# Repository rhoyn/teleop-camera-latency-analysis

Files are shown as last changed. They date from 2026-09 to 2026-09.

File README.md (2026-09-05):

# teleop-camera-latency-analysis

Blog post: [Low latency eyes](https://rhoyn.com/low-latency-eyes?utm_source=github)

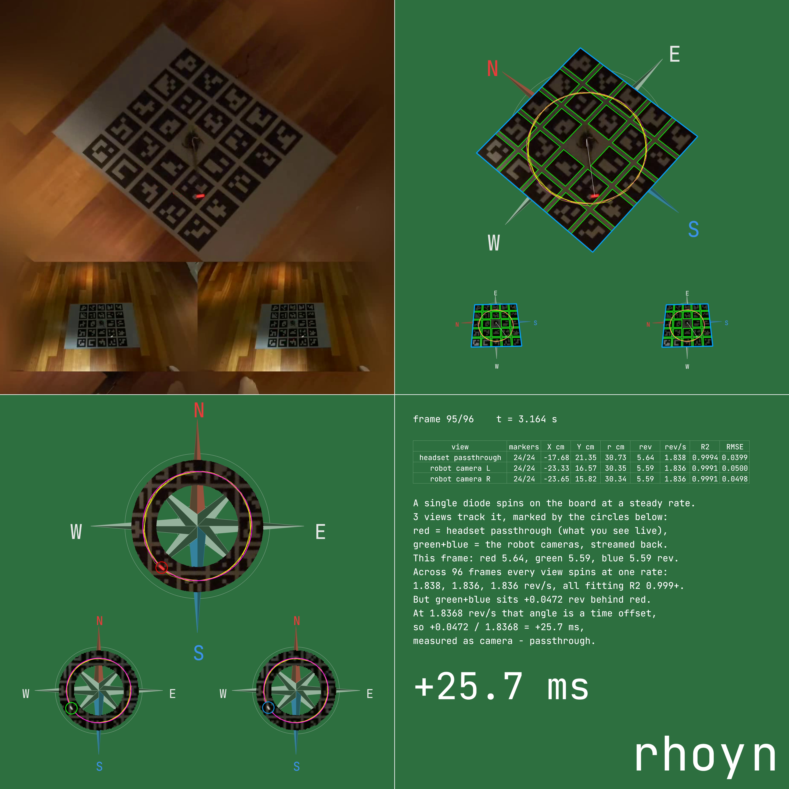
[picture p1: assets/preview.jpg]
The four-panel output: the raw view, the fitted overlay, the diode's orbit band, and the measurement table with the latency


https://github.com/user-attachments/assets/50d515f3-5a79-4a9a-a9fb-55cd01d475e2

## Problem statement

This is what the operator sees while teleoperating the humanoid: the room in
front of them through the headset's own passthrough, with the robot's cameras
floating inside it. Both show the same scene from almost the same place, and
that is what makes the lag visible — move, and the robot's view of the move
arrives a little after the live one.

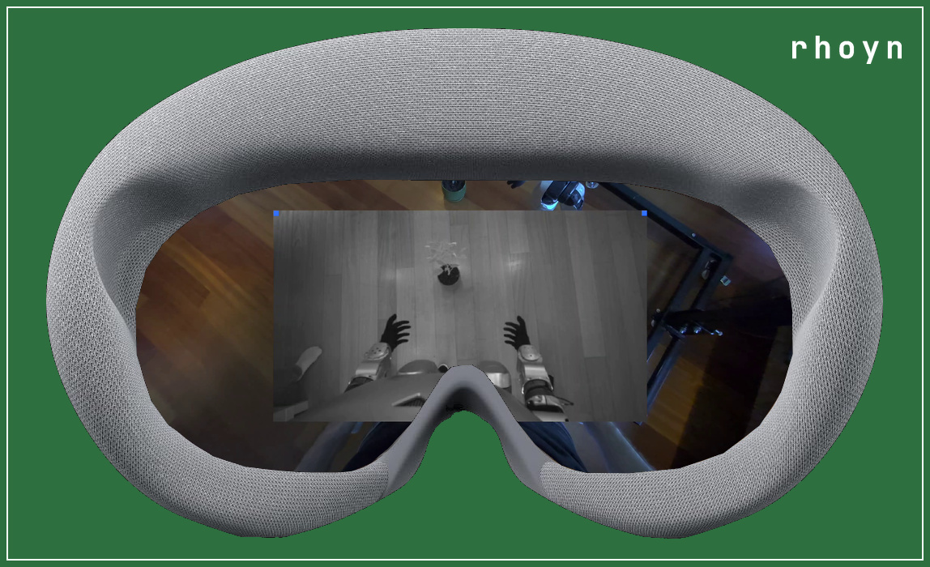
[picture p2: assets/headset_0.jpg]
Inside the headset while teleoperating: the passthrough view of the room, with the robot's camera feed floating in the middle of it showing the same floor and the robot's own hands


The robot feed is stereo, a separate image per eye, which is what gives it
depth and exactly what a flat screen cannot reproduce. It can be switched to a
side-by-side pair of the two eyes, which is what a screenshot can show:

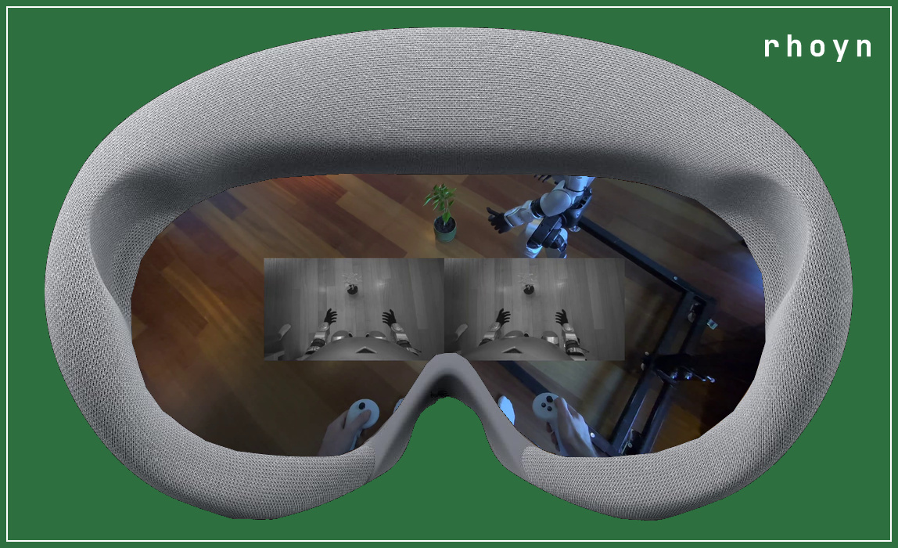
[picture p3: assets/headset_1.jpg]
The same view switched out of stereo: the robot's left and right camera images shown side by side rather than one per eye


Noticing the lag is not measuring it. For that the floor gets one printed ArUco
board with an LED on an arm spinning around its centre, and the session is
recorded through the headset. A single frame of that recording holds the whole
measurement:

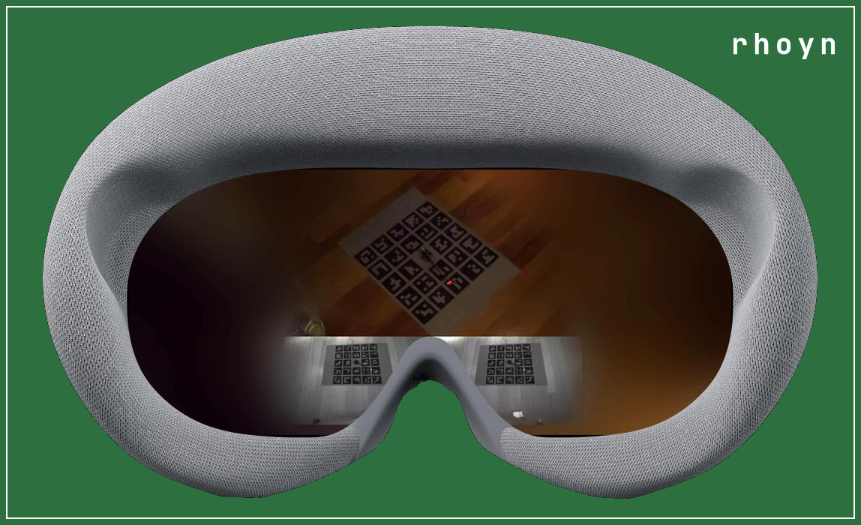
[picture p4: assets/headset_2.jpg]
A single frame of one recording, made inside the headset: the passthrough view of the board on the floor with the spinning LED lit red, and the robot cameras' stereo preview floating below it, showing the same board as it arrives over the teleoperation stack


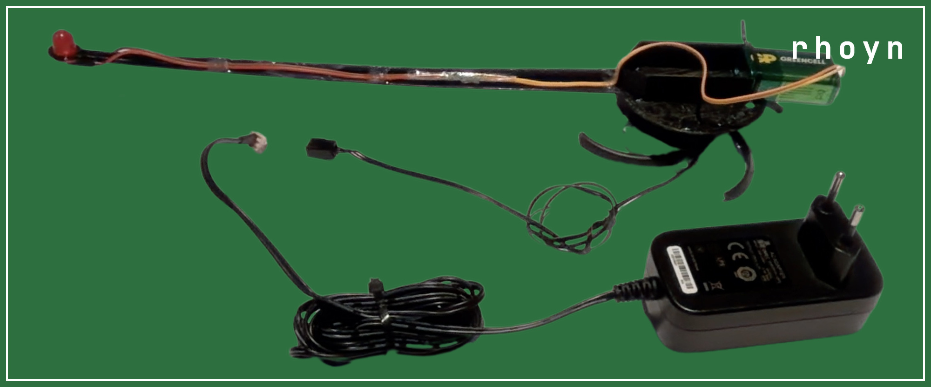
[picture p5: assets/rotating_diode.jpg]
The assembled spinning arm: a red LED at the tip of the printed arm, the battery that powers it strapped to the hub, and the motor and its supply


That recording is what this software processes.

## What it measures

Measures end-to-end video latency of a teleoperation stack from a single
recording, by watching one physical spinning LED through every camera path at
once.

The program prints one number — the latency in milliseconds — on stdout, and
writes a four-panel video showing how it got there.

The number is signed, always as **camera minus passthrough**: positive means the
robot camera view is that far behind the live passthrough, negative means it is
that far ahead. A stream fast enough to tie with the headset's own passthrough
sits near zero and its sign will wander between clips, which is what a reading
below the method's noise floor looks like — treat a small number as "no
measurable difference", not as a confident lead.

## Capture rig

- `aruco_board_A0.pdf` — the marker board, printed at A0. It is a 5x5 grid
  from `DICT_4X4_50` with the centre marker omitted to leave room for the
  spinning arm's axle. The dimensions the program assumes are compiled in near
  the top of `main.cpp` (`BOARD_WIDTH_CM`, `MARKERS_PER_SIDE`, and the rest);
  if you print at a different size, change them to match.
- `rotating_diode/` — the spinning arm, as OpenSCAD source plus prebuilt STLs.
  `rotating_diode/run.sh` regenerates the STLs (whole, plus split left/right
  halves for smaller print beds). It carries a battery and a red LED, and the
  program expects the LED to orbit at `DIODE_ORBIT_RADIUS_CM`. The parts and
  the motor it spins on are listed in
  [rotating_diode/BOM.md](rotating_diode/BOM.md).

The arm's exact speed doesn't need to be known or held constant between runs —
it's measured from the video, and only has to be steady across a single clip.

## How it works

The subject is one printed ArUco board with an LED on an arm spinning around
its centre, and one frame of the headset recording holds that board twice over,
or three times for a stereo pair:

- the **headset passthrough** — the operator's own view of the room, as close
  to realtime as the headset gets, showing the LED roughly where it is now,
  and
- the **robot camera** preview floating in front of it (here a stereo
  **L**/**R** pair) — the same LED, but arriving over the teleoperation
  stack, so showing where it was some milliseconds ago.

One recorder, one instant, one physical LED. Nothing has to be instrumented
and no clocks have to be synchronised: the only thing separating the two
pictures of the board is the latency of the stream between them.

The LED spinning is what turns that separation into a number. Where the arm
points is a clock hand, and the two views are reading the same hand at
different moments, so the angle between them is the delay — once the arm's
speed is known, and that is measured from the video too.

For each frame the program fits the board pose from the ArUco markers, maps
the LED blob into board coordinates, and records its angle. Unwrapped over the
clip, each view's angle-versus-time is a straight line. All views share the
same angular speed — it's one physical LED — so the fitted lines differ only
in phase. Dividing that phase gap by the shared angular speed converts it into
time, and fitting over every frame rather than comparing frame to frame is
what averages the per-frame noise out.

Fitting the whole clip is also why the result has sub-frame resolution: the
measurement is not quantised to the recording's frame interval.

## Results

Every clip in `inputs/`, in milliseconds, signed as **camera minus
passthrough**: positive means the robot camera view sits that far behind the
live passthrough. Row `3` is `inputs/<stack>-3.mp4`, and its four-panel render
is `outputs/<stack>-3.mp4`.

| # | rhoyn | XRoboToolkit |
|---|---|---|
| 0 | -4.3 | +25.7 |
| 1 | -2.4 | +31.7 |
| 2 | +6.9 | +40.5 |
| 3 | -2.7 | +39.7 |
| 4 | +5.5 | +41.2 |
| 5 | -1.8 | +28.7 |
| 6 | -3.8 | +35.0 |
| 7 | +3.1 | +35.6 |
| **median** | **-2.1** | **+35.3** |
| **mean** | **+0.1** | **+34.8** |

### Comparison

| video stack | recordings | median latency | vs rhoyn |
|---|---|---|---|
| rhoyn Teleop + stock Unitree G1 D435 | 8 | **-2.1 ms** | — |
| XRoboToolkit Orin Video Sender + ZED Mini | 8 | **+35.3 ms** | **+37.4 ms slower** |

The two stacks do not overlap: rhoyn spans -4.3 to +6.9 ms and the alternative
+25.7 to +41.2 ms, so every rhoyn clip is ahead of every clip from the
alternative.

The last column is a difference rather than the "Nx slower" ratio the hands
analysis uses, because a ratio would be meaningless here. rhoyn's clips
straddle zero and their sign wanders between takes, which is exactly what a
stream fast enough to tie with the headset's own passthrough looks like — so
-2.1 ms means "no measurable difference", not a 2 ms lead, and dividing by a
figure sitting on the noise floor would manufacture a ratio out of nothing.
What the recordings do support is the gap: the alternative arrives about 37 ms
behind.

### How much lower

Pair every rhoyn clip with every clip from the alternative — 8 x 8, so 64
pairs — subtract, and take the median of the 64 differences. That number is
**34.7 ms**: the alternative's display latency is 34.7 ms higher than rhoyn's.

Both stacks were recorded the same way and measured by this program with the
same board and the same constants, so every one of those 64 subtractions is
between two numbers produced by one instrument. All 64 come out positive,
the smallest 18.8 ms and the largest 45.5 ms, because the two sets of clips
do not overlap.

## Build and run

```sh
make                       # -> build/teleop-camera-latency-analysis
./run.sh                   # every clip in inputs/, results into outputs/
./run.sh inputs/clip.mp4   # or specific clips
```

Or directly:

```sh
build/teleop-camera-latency-analysis --input inputs/clip.mp4 --output outputs/clip.mp4
```

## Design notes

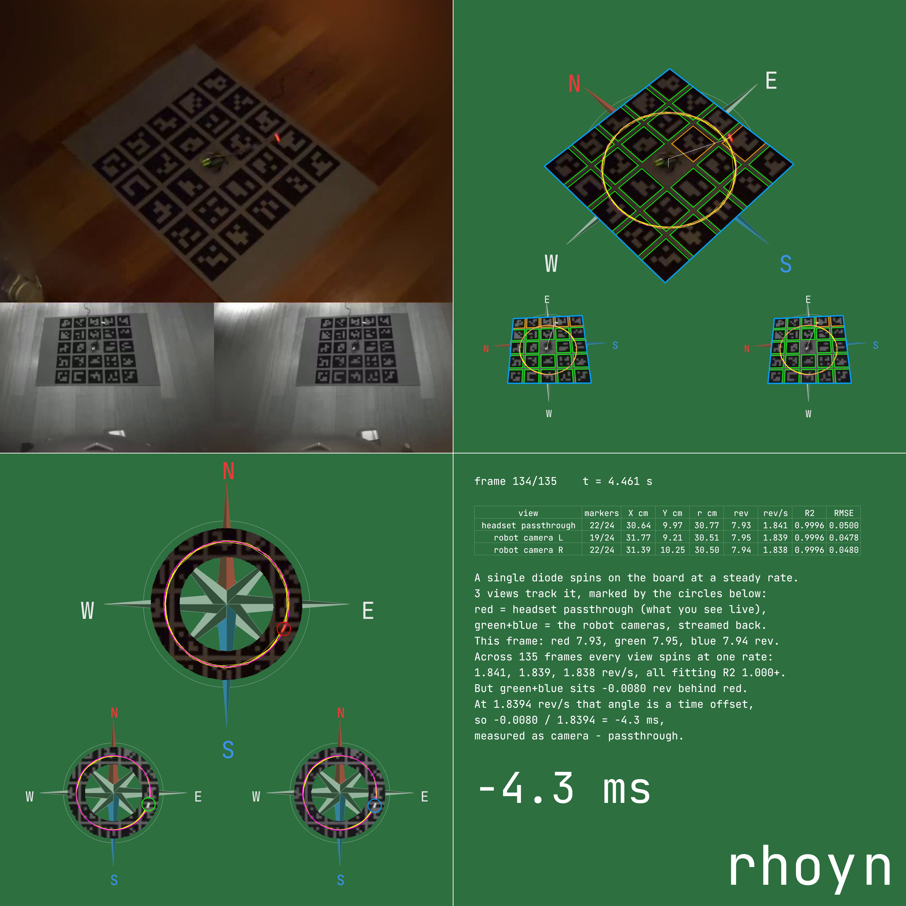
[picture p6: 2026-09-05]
assets/preview_rhoyn.jpg

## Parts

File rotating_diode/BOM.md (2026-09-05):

# Rotating diode — bill of materials

Everything needed to build the spinning arm and the motor that turns it.

| # | Part | Notes |
|---|---|---|
| 1 | Printed arm | `rotating_diode.stl`, or `rotating_diode_left.stl` + `rotating_diode_right.stl` glued at the cut plane for smaller beds |
| 2 | 10 mm red LED | Press-fits the 10.5 mm hole at the tip of the arm; this is the blob the program tracks |
| 3 | Resistor, 270 Ω | 5-band, red-violet-black-black-brown (2-7-0, x1, +/-1%). In series with the LED |
| 4 | 9 V battery | Rides in the walled pocket on the disk and turns with it, so no slip ring is needed |
| 5 | 9 V battery clip | Snap connector, wires run along the arm to the LED |
| 6 | 120 x 120 mm fan | The motor — see below |
| 7 | 12 V DC power supply | Drives the fan. A barrel-jack adapter with a fan connector, or any 12 V supply wired to the fan's two power leads |
| 8 | Glue and tape | To bond the arm to the fan hub and dress the LED wiring down the arm |

## The motor

The fan is used as a bare motor, not as a fan:

1. Cut away the square frame, leaving the hub and its spider.
2. Remove the blades from the hub.
3. Glue the bottom of the printed disk to the hub.

Powered from the 12 V supply, the hub spins the arm. The speed doesn't need to
be set or known — it's measured from the video, and only has to stay steady
across a single clip.

## The LED circuit

Battery -> clip -> 270 Ω resistor -> LED -> back to the battery. At 9 V with a
red LED that's roughly 26 mA, which is bright enough to saturate in the
recordings while staying inside a 10 mm LED's rating. The whole circuit rotates
with the arm, so nothing has to be fed across the rotating joint.

The assembled arm, motor hub and 12 V supply

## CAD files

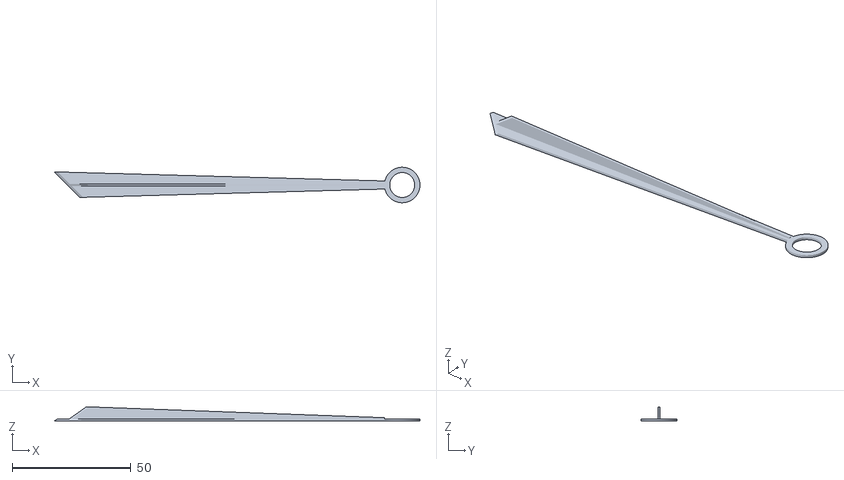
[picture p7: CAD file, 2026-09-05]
rotating_diode/rotating_diode_right.stl
154.4 x 15.0 x 6.10

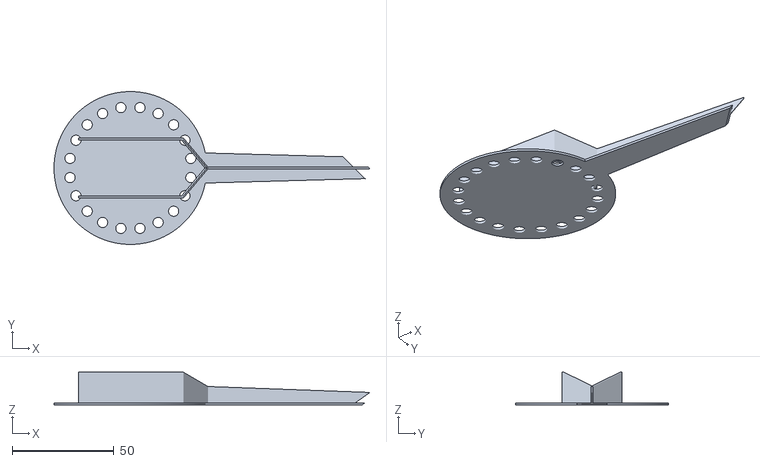
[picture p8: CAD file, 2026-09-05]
rotating_diode/rotating_diode_left.stl
155.1 x 75.0 x 16.0

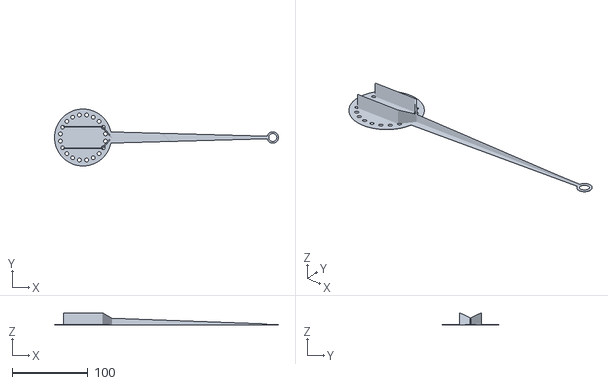
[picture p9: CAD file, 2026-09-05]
rotating_diode/rotating_diode.stl
295.0 x 75.0 x 16.0

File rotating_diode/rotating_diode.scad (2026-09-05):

$fn = 180;

disk_dia            = 75;
disk_h              = 1;
disk_hole_dia       = 5;
disk_hole_count     = 20;
disk_hole_edge_gap  = 5;
disk_hole_ring_r    = disk_dia / 2 - disk_hole_edge_gap - disk_hole_dia / 2;

battery_len    = 50;
battery_width  = 26.5;
fit_clearance  = 1.0;
wall_th        = 1;
wall_h         = 15;
wall_len       = battery_len + fit_clearance;
wall_y         = (battery_width + fit_clearance) / 2 + wall_th / 2;

stick_tip_x    = 250;
stick_w_base   = 15;
stick_w_tip    = 3;
stick_overlap  = 5;
stick_base_x   = disk_dia / 2 - stick_overlap;
tip_pad_dia    = 15;
tip_hole_dia   = 10.5;
rib_w          = 1;
rib_h_base     = 8;
rib_h_tip      = 0.5;
rib_base_x     = disk_dia / 2;
rib_tip_x      = stick_tip_x - tip_pad_dia / 2;

cut_x     = (-disk_dia / 2 + stick_tip_x + tip_pad_dia / 2) / 2;
cut_w     = 0.1;
cut_yaw   = 45;
cut_tilt  = 45;

module disk() {
    difference() {
        cylinder(h = disk_h, d = disk_dia);
        for (i = [0 : disk_hole_count - 1]) {
            angle = (i + 0.5) * 360 / disk_hole_count;
            translate([disk_hole_ring_r * cos(angle), disk_hole_ring_r * sin(angle), -1])
                cylinder(h = disk_h + 2, d = disk_hole_dia);
        }
    }
}

module battery_walls() {
    for (side = [1, -1])
        translate([0, side * wall_y, disk_h + wall_h / 2])
            cube([wall_len, wall_th, wall_h], center = true);
}

module stick() {
    difference() {
        union() {
            linear_extrude(height = disk_h)
                polygon([[stick_base_x,  stick_w_base / 2],
                         [stick_tip_x,   stick_w_tip / 2],
                         [stick_tip_x,  -stick_w_tip / 2],
                         [stick_base_x, -stick_w_base / 2]]);
            translate([stick_tip_x, 0, 0])
                cylinder(h = disk_h, d = tip_pad_dia);
            translate([0, rib_w / 2, disk_h])
                rotate([90, 0, 0])
                    linear_extrude(height = rib_w)
                        polygon([[rib_base_x, 0],
                                 [rib_tip_x,  0],
                                 [rib_tip_x,  rib_h_tip],
                                 [rib_base_x, rib_h_base]]);
        }
        translate([stick_tip_x, 0, -1])
            cylinder(h = disk_h + 2, d = tip_hole_dia);
    }
}

module rib_wall_braces() {
    for (side = [1, -1])
        hull() {
            translate([rib_base_x, 0, disk_h + rib_h_base / 2])
                cube([rib_w, rib_w, rib_h_base], center = true);
            translate([wall_len / 2, side * wall_y, disk_h + wall_h / 2])
                cube([wall_th, wall_th, wall_h], center = true);
        }
}

module at_cut_plane() {
    translate([cut_x, 0, disk_h])
        rotate([0, cut_tilt, cut_yaw])
            children();
}

module assembly() {
    difference() {
        union() {
            disk();
            battery_walls();
            stick();
            rib_wall_braces();
        }
        at_cut_plane()
            cube([cut_w, disk_dia + 20, (disk_h + wall_h) * 4], center = true);
    }
}

module half(side) {
    intersection() {
        assembly();
        at_cut_plane()
            translate([side == "left" ? -1000 : 0, -500, -500])
                cube([1000, 1000, 1000]);
    }
}

part = "all";

if      (part == "left")  half("left");
else if (part == "right") half("right");
else                      assembly();

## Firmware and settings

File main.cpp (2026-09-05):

#include <opencv2/geometry.hpp>
#include <opencv2/objdetect/aruco_detector.hpp>
#include <opencv2/freetype.hpp>
#include <opencv2/imgproc.hpp>
#include <opencv2/videoio.hpp>

#include <algorithm>
#include <array>
#include <cmath>
#include <condition_variable>
#include <cstdarg>
#include <cstdio>
#include <deque>
#include <filesystem>
#include <malloc.h>
#include <linux/limits.h>
#include <unistd.h>
#include <limits>
#include <map>
#include <mutex>
#include <numeric>
#include <optional>
#include <set>
#include <stdexcept>
#include <string>
#include <thread>
#include <utility>
#include <vector>

#if CV_VERSION_MAJOR < 5
#error "requires OpenCV 5 or newer: aruco lives in objdetect"
#endif

namespace {

/**
 * Markers along one edge of the printed board.
 *
 * The board is a 5x5 grid with the centre omitted, so 24 markers carry the
 * pose. Changing this alone is not enough: the printed PDF, the marker ids
 * and `MODULES_ACROSS` all describe the same sheet and have to agree.
 */
constexpr int MARKERS_PER_SIDE = 5;

/**
 * Dictionary id of the board's top-left marker.
 *
 * Ids run consecutively from here in reading order, which is what lets a
 * detected id be turned back into a board coordinate by arithmetic alone.
 */
constexpr int FIRST_MARKER_ID = 5;

/**
 * The id the centre of the grid would have carried.
 *
 * That square is left blank so the spinning arm's axle has somewhere to sit
 * without covering a marker. It is skipped when the board model is built.
 */
constexpr int EMPTY_CENTER_ID = 17;

/**
 * ArUco modules across the printed sheet, markers and quiet zones together.
 *
 * The physical size divided by this gives the module pitch, which is how the
 * cm-space marker layout below is derived from one measurement of the sheet.
 */
constexpr int MODULES_ACROSS = 34;

/**
 * Printed width of the marker sheet, in centimetres.
 *
 * Measured from the sheet rather than taken from the page size, because A0
 * paper and the printer's margins do not agree to the millimetre and every
 * distance in board space is scaled by this.
 */
constexpr double BOARD_WIDTH_CM = 79.5;

/**
 * Printed height of the marker sheet, in centimetres.
 *
 * Not equal to the width: the same nominal square comes off the printer
 * slightly anisotropic, and keeping the two apart is what stops that error
 * from leaking into the fitted orbit radius.
 */
constexpr double BOARD_HEIGHT_CM = 79.3;

/** Horizontal size of one ArUco module, in centimetres. */
constexpr double MODULE_X_CM = BOARD_WIDTH_CM / MODULES_ACROSS;

/** Vertical size of one ArUco module, in centimetres. */
constexpr double MODULE_Y_CM = BOARD_HEIGHT_CM / MODULES_ACROSS;

/** Marker width in centimetres; a `DICT_4X4` marker is six modules across. */
constexpr double MARKER_WIDTH_CM = 6.0 * MODULE_X_CM;

/** Marker height in centimetres, six modules like the width. */
constexpr double MARKER_HEIGHT_CM = 6.0 * MODULE_Y_CM;

/** Centre-to-centre spacing in x: six modules of marker plus one of gap. */
constexpr double PITCH_X_CM = 7.0 * MODULE_X_CM;

/** Centre-to-centre spacing in y, matching `PITCH_X_CM`. */
constexpr double PITCH_Y_CM = 7.0 * MODULE_Y_CM;

/**
 * Half the board width, the x offset that puts the origin at its centre.
 *
 * Board space is centred on the axle rather than on a corner, so the diode's
 * orbit is a circle about the origin and its angle needs no further offset.
 */
constexpr double HALF_WIDTH_CM = BOARD_WIDTH_CM / 2.0;

/** Half the board height, the matching y offset for a centred origin. */
constexpr double HALF_HEIGHT_CM = BOARD_HEIGHT_CM / 2.0;

/**
 * Height of the LED above the printed sheet, in centimetres.
 *
 * The homography maps the board plane, not the plane the LED orbits in, so a
 * blob seen off-axis lands slightly outside its true radius. This is what the
 * correction uses to project it back down.
 */
constexpr double DIODE_HEIGHT_CM = 4.0;

/**
 * Dictionary the printed markers were generated from.
 *
 * 4x4 keeps the modules large enough to survive the robot camera's downscaled
 * preview, where a denser dictionary stops decoding first.
 */
constexpr int ARUCO_DICTIONARY = cv::aruco::DICT_4X4_50;

/**
 * Slack added around a view's marker bounds before searching it, in pixels.
 *
 * The crop follows the markers, but the diode orbits outside them and the
 * board drifts between frames. Too little padding and the LED leaves the
 * search window on a fast take; the cost of too much is only search time.
 */
constexpr int CROP_PADDING_PX = 260;

/**
 * Extra margin around a tracked board, in multiples of its marker pitch.
 *
 * Expressed in markers rather than pixels so it scales with however large the
 * board appears in that view: the robot preview is a quarter the size of the
 * passthrough and needs the same proportional margin, not the same one.
 */
constexpr double TRACK_MARGIN_MARKERS = 0.5;

/**
 * Factor the frame is shrunk by for the initial view-finding scan.
 *
 * Locating the boards only needs to be approximate, and detection on a
 * quarter-size image is roughly an order of magnitude cheaper. The full
 * resolution frame is used once the crops are known.
 */
constexpr int CROP_SCAN_DOWNSCALE = 4;

/**
 * Time constant of the crop's exponential smoother, in seconds.
 *
 * Converted to a per-frame alpha against the clip's own fps, so the crop
 * settles at the same rate in wall-clock terms whatever the recording ran at.
 * It is deliberately slow: a crop that chases per-frame jitter makes the
 * overlay panels shimmer.
 */
constexpr double CROP_SMOOTHING_SECONDS = 1.0;

/** Fraction the smoothed crop is grown by, so the board never touches its edge. */
constexpr double CROP_SLACK = 0.12;

/**
 * Time skipped at each end of the clip, in seconds.
 *
 * Both ends: a recording usually starts with the operator still settling and
 * ends with them reaching for the stop, and neither stretch is the steady
 * rotation the fit assumes.
 */
constexpr double WARMUP_SECONDS = 0.5;

/**
 * Seed forced into OpenCV's global RNG before the run.
 *
 * `findHomography` with RANSAC samples that generator, so without a fixed
 * seed the same clip yields slightly different numbers on every run. Pinning
 * it is what makes a reported latency reproducible.
 */
constexpr uint64_t RANDOM_SEED = 0;

/**
 * Radius the LED orbits at, in centimetres.
 *
 * Only a starting point for the annular search band; the radius actually used
 * is fitted from the track, so a differently built arm still measures.
 */
constexpr double DIODE_ORBIT_RADIUS_CM = 30.0;

/**
 * Width of the annulus the LED is searched in, in centimetres.
 *
 * Tied to the marker size rather than chosen outright, so a board printed at
 * a different scale widens the band by the same factor and the search keeps
 * the same tolerance in board units.
 */
constexpr double DIODE_BAND_WIDTH_CM = MARKER_WIDTH_CM;

/** Inner edge of the search annulus. */
constexpr double DIODE_INNER_RADIUS_CM =
    DIODE_ORBIT_RADIUS_CM - DIODE_BAND_WIDTH_CM / 2.0;

/** Outer edge of the search annulus. */
constexpr double DIODE_OUTER_RADIUS_CM =
    DIODE_ORBIT_RADIUS_CM + DIODE_BAND_WIDTH_CM / 2.0;

/**
 * Reach of the compass star's cardinal arms, in centimetres.
 *
 * The star is decoration drawn in board space, so sizing it from the orbit
 * radius keeps it in proportion to the board in every view without a
 * per-view constant.
 */
constexpr double COMPASS_POINT_CM = DIODE_ORBIT_RADIUS_CM * 2.0;
constexpr double COMPASS_DIAGONAL_CM =
    COMPASS_POINT_CM * 0.62;  ///< reach of the four diagonal arms
constexpr double COMPASS_OUTER_RING_CM =
    COMPASS_POINT_CM * 0.68;  ///< radius of the outer ring
constexpr double COMPASS_INNER_RING_CM =
    COMPASS_POINT_CM * 0.20;  ///< radius of the inner ring
constexpr double COMPASS_SHOULDER_CM =
    COMPASS_POINT_CM * 0.11;  ///< where an arm's flanks meet its neighbours
constexpr double COMPASS_LABEL_CM =
    COMPASS_POINT_CM * 1.14;  ///< radius the N/E/S/W labels sit at
constexpr double COMPASS_LABEL_HEIGHT_CM =
    COMPASS_POINT_CM * 0.19;  ///< label cap height in board units

/**
 * Weight the compass star is blended into the panel at.
 *
 * Drawn onto a copy and blended back rather than painted directly, so the
 * board stays readable underneath it and the star never hides a marker the
 * reader is trying to check.
 */
constexpr double COMPASS_OPACITY = 0.55;

/**
 * Vertical placement of the top view's band, as a fraction of the panel.
 *
 * The band panel shows each view's annulus at a fixed spot rather than where
 * the board happens to be, so the three views can be compared side by side.
 */
constexpr double BAND_TOP_CENTRE_Y = 1.0 / 3.0;
constexpr double BAND_BOTTOM_CENTRE_Y =
    3.0 / 4.0;  ///< vertical placement of the bottom views' bands
constexpr double BAND_TOP_DIAMETER =
    1.0 / 3.0;  ///< top view's band diameter, as a fraction of the panel
constexpr double BAND_BOTTOM_DIAMETER =
    1.0 / 5.0;  ///< bottom views' band diameter; two must fit side by side

constexpr int COMPASS_POINTS = 8;  ///< four cardinal arms and four diagonals
constexpr int COMPASS_NORTH_STEP = 0;  ///< which arm is coloured as north
constexpr int COMPASS_SOUTH_STEP = 4;  ///< which arm is coloured as south

/**
 * Smallest cap height a compass label is drawn at, in pixels.
 *
 * Below this the glyphs are illegible smudges, so the labels are dropped
 * rather than drawn: the robot preview is small enough for that to happen.
 */
constexpr int COMPASS_LABEL_MIN_PX = 7;

/**
 * Lowest redness score accepted as the LED, on a 0-255 scale.
 *
 * The first pass looks for the diode by colour. A frame whose peak falls
 * short is not treated as a weak detection but as none at all, and the
 * brightness search runs instead.
 */
constexpr int RED_LED_MIN_SCORE = 25;

/**
 * Chroma below which a view is treated as greyscale.
 *
 * The robot cameras deliver infrared, so their preview carries no colour and
 * the red-LED search cannot work there. Measuring the chroma decides which of
 * the two searches a view gets, rather than hard-coding which view is which.
 */
constexpr double GRAY_CHROMA_LIMIT = 6.0;

/**
 * Brightness cut-offs tried in turn when looking for the LED in a grey view.
 *
 * Descending, and the first that yields a blob of plausible area wins. A
 * single threshold cannot serve both a bright passthrough and a dim infrared
 * preview; walking down from the brightest keeps the strongest candidate
 * rather than the largest.
 */
const std::array<int, 7> BRIGHT_THRESHOLDS{235, 220, 205, 190, 175, 160, 145};
constexpr int BRIGHT_MIN_AREA = 2;  ///< smaller blobs are sensor noise
constexpr int BRIGHT_MAX_AREA =
    1500;  ///< larger blobs are a lamp or a reflection, not the LED

/**
 * Weight a new frame's board pose is mixed in at.
 *
 * The pose is re-fitted every frame and would otherwise jitter by a pixel or
 * two, which is visible in the overlay. Only the drawing is smoothed; the
 * angles the measurement is built from come from the unsmoothed fit.
 */
constexpr double POSE_SMOOTHING = 0.1;
constexpr int TABLE_COLUMNS = 9;  ///< columns in the results table panel

/**
 * Fractional bits used by the drawing calls.
 *
 * OpenCV takes integer coordinates, so lines drawn from board space would
 * otherwise snap to whole pixels and the fitted circle would look polygonal.
 * Shifting gives 1/16th-pixel placement.
 */
constexpr int DRAW_SHIFT = 4;
constexpr int PANEL_SIZE =
    720;  ///< edge of one panel in the output grid, in pixels
constexpr int OUTPUT_WIDTH = PANEL_SIZE * 2;   ///< two panels across
constexpr int OUTPUT_HEIGHT = PANEL_SIZE * 2;  ///< two panels down

/**
 * Overlay palette, in OpenCV's BGR order.
 *
 * `VIEW_COLORS` picks one per view so a reader can tell at a glance which
 * board a drawing belongs to; the rest label fixed parts of the overlay.
 */
const cv::Scalar GREEN{0, 255, 0};
const cv::Scalar GRID{130, 170, 120};   ///< the projected marker grid
const cv::Scalar YELLOW{0, 255, 255};   ///< the fitted orbit circle
const cv::Scalar RED{0, 0, 255};        ///< view 0, and the diode marker
const cv::Scalar MAGENTA{255, 0, 255};  ///< the detected diode blob
const cv::Scalar SITE_GREEN{
    64,
    111,
    46
};  ///< the brand green the numbers panel is painted in
const cv::Scalar WHITE{255, 255, 255};  ///< text
const cv::Scalar ORANGE{0, 165, 255};   ///< warnings in the results table
const cv::Scalar BLUE{255, 160, 0};     ///< view 2
const cv::Scalar COMPASS_LIGHT{232, 232, 232};  ///< lit facet of a compass arm
const cv::Scalar COMPASS_DARK{54, 54, 54};  ///< shaded facet of a compass arm
const cv::Scalar COMPASS_NORTH_LIGHT{
    58,
    58,
    236
};  ///< lit facet of the north arm
const cv::Scalar COMPASS_NORTH_DARK{
    34,
    34,
    118
};  ///< shaded facet of the north arm
const cv::Scalar COMPASS_SOUTH_LIGHT{
    236,
    146,
    58
};  ///< lit facet of the south arm
const cv::Scalar COMPASS_SOUTH_DARK{
    124,
    74,
    30
};  ///< shaded facet of the south arm
const std::array<const char*, 4> COMPASS_LABELS{
    "N",
    "E",
    "S",
    "W"
};  ///< cardinals, in compass-step order

/** One colour per view, so every drawing says which board it came from. */
const std::array<cv::Scalar, 3> VIEW_COLORS{RED, GREEN, BLUE};

/** Those colours by name, for the results table's legend column. */
const std::array<const char*, 3> VIEW_COLOR_NAMES{"red", "green", "blue"};

/**
 * Overlay font, relative to the executable rather than the process's cwd.
 *
 * Resolved against the binary's own directory and its parent, so the tool
 * runs from anywhere as long as `assets/` travels with it.
 */
const char* FONT_PATH = "assets/JetBrainsMono.ttf";

/**
 * Body text size on the reference 1920px-wide page, in points.
 *
 * The panels are laid out at 1920 and rendered at `PANEL_SIZE`, so sizes are
 * written once against the reference page and scaled on the way out.
 */
constexpr double PAGE_SIZE_TEXT = 17.0;
constexpr double PAGE_SIZE_DISPLAY =
    88.0;  ///< display size on the same reference page
constexpr double PAGE_TRACKING =
    0.18;  ///< letter spacing of the wordmark, as a fraction of cap height

/** Body text cap height in output pixels, scaled from the reference page. */
constexpr int TEXT_HEIGHT =
    static_cast<int>(PAGE_SIZE_TEXT * 1920 / PANEL_SIZE);

/** Wordmark cap height, in the same ratio to the body text as on the page. */
constexpr int LOGO_HEIGHT =
    static_cast<int>(TEXT_HEIGHT * (PAGE_SIZE_DISPLAY / PAGE_SIZE_TEXT));

constexpr int TEXT_LINE =
    TEXT_HEIGHT * 3 / 2;                      ///< baseline-to-baseline spacing
constexpr int TEXT_MARGIN = TEXT_HEIGHT * 2;  ///< panel padding
const char* LOGO_TEXT = "rhoyn";  ///< wordmark drawn on the numbers panel

/**
 * Index of the headset passthrough among the views.
 *
 * The passthrough is the reference every latency is measured against, and
 * `cluster_boards` orders views topmost first, which is what puts it here.
 */
constexpr int TOP_VIEW = 0;

/**
 * Number of board views in the recording.
 *
 * Not constant: `configure_views` sets it once the first frames reveal
 * whether the robot camera is mono or stereo, so neither case needs a flag.
 */
int VIEW_COUNT = 3;
bool TWO_BOTTOM_BOARDS = true;  ///< true when the robot camera is a stereo pair

/** View labels for the overlay and the results table, in view order. */
std::vector<const char*> VIEW_NAMES{
    "headset passthrough",
    "robot camera L",
    "robot camera R"
};

/** Views that are robot cameras, i.e. everything but the passthrough. */
std::vector<int> BOTTOM_VIEWS{1, 2};

/** Stands for a measurement a frame did not produce. */
const double NaN = std::numeric_limits<double>::quiet_NaN();
std::string INPUT_PATH = "input.mp4";  ///< recording to read, from `--input`
std::string OUTPUT_PATH =
    "output.mp4";  ///< four-panel render to write, from `--output`

/**
 * Frames the encoder thread may hold before the analysis has to wait.
 *
 * Encoding is slower than analysis, so a queue keeps both busy; a bound is
 * what stops a long clip from growing the queue until it exhausts memory.
 */
constexpr size_t WRITER_QUEUE_FRAMES = 8;

/**
 * One board as this frame saw it.
 *
 * The homography is stored image-to-board because that is the direction the
 * measurement needs: a diode found in pixels becomes a position in
 * centimetres. Drawing inverts it.
 */
struct ViewGeometry {
  std::vector<std::vector<cv::Point2f>> corners;
  std::vector<int> ids;
  cv::Mat image_to_board;
};

/** Every view's geometry for one frame, indexed by view. */
using FrameGeometry = std::vector<ViewGeometry>;

/**
 * Where the LED was found in one view, in both spaces.
 *
 * The pixel track is kept alongside the board-space one so the overlay can
 * mark the raw detection rather than a reprojection of the fitted value.
 */
struct DiodeTrack {
  std::vector<cv::Point2d> pixels;
  std::vector<cv::Point2d> positions_cm;
};

/** A fitted orbit: centre and radius, in board centimetres. */
struct Circle {
  cv::Point2d center;
  double radius = 0.0;
};

/**
 * One view's straight-line fit of unwrapped angle against time.
 *
 * The slope is the angular speed and the intercept the phase, and it is the
 * difference between two views' intercepts that becomes a latency. `r2` and
 * `rmse` are carried for the table so a poor fit is visible rather than
 * silently averaged in.
 */
struct RegressionFit {
  double slope = 0.0;
  double intercept = 0.0;
  double r2 = 0.0;
  double rmse = 0.0;
};

/** The finished measurement: the shared speed, the fits, and the number. */
struct LatencyResult {
  double omega = 0.0;
  double latency_ms = 0.0;
  std::vector<RegressionFit> fits;
  int paired_frames = 0;
};

/**
 * The ArUco detector, the board model and the contrast equaliser.
 *
 * Built once and reused: constructing a detector per frame dominates the
 * per-frame cost, and CLAHE is what lets the dim infrared preview decode at
 * the same settings as the bright passthrough.
 */
struct Detector {
  cv::aruco::ArucoDetector aruco;
  cv::aruco::Board board;
  cv::Ptr<cv::CLAHE> clahe;
};

/** An inclusive pixel rectangle within the frame. */
struct CropBox {
  int x0 = 0, y0 = 0, x1 = 0, y1 = 0;
};

/** What the container claims about the clip: rate, length and frame size. */
struct VideoInfo {
  double fps = 24.0;
  int frame_count = 0;
  cv::Size size;
};

/**
 * Exponentially smoothed crop for one view.
 *
 * Centre and side are smoothed rather than the four edges, so the window
 * keeps its shape while it follows the board instead of breathing.
 */
struct CropSmoother {
  bool initialised = false;
  double cx = 0.0;
  double cy = 0.0;
  double side = 0.0;
};

/**
 * Normal equations for a circle fit that never stores the samples.
 *
 * The orbit is fitted algebraically, so each new point only has to update a
 * 3x3 matrix and a vector. That keeps memory flat over a long clip and lets
 * the current best circle be read out at any frame for the overlay.
 */
struct RunningCircle {
  cv::Matx33d ata = cv::Matx33d::zeros();
  cv::Vec3d atb = cv::Vec3d::all(0.0);
  int count = 0;
  Circle circle;
};

/** Running sums for a least-squares line, again without keeping the samples. */
struct RunningRegression {
  double n = 0.0, sx = 0.0, sxx = 0.0, sy = 0.0, sxy = 0.0, syy = 0.0;
};

/**
 * State for turning wrapped angles into a continuous one.
 *
 * The measured angle lives in (-pi, pi] and the fit needs it to keep
 * climbing, so each step's wrap is detected and folded into a correction.
 */
struct RunningUnwrap {
  bool has_previous = false;
  double previous_raw = 0.0;
  double correction = 0.0;
};

/**
 * Which way the arm turns, decided once and then held.
 *
 * Locked on the first usable step rather than re-derived per frame: a single
 * noisy step near a wrap would otherwise flip the sign and unwrap the rest of
 * the clip backwards.
 */
struct RotationSign {
  bool locked = false;
  double value = 1.0;
};

/**
 * Encoder running on its own thread, with a bounded pool of frame buffers.
 *
 * Encoding costs more than analysing, so it is moved off the analysis thread.
 * Buffers are recycled through `spare` rather than reallocated per frame, and
 * `allocated` bounds the pool so a slow encoder applies backpressure instead
 * of consuming memory.
 */
struct BackgroundWriter {
  cv::VideoWriter video;
  std::thread encoder;
  std::mutex mutex;
  std::condition_variable frame_queued;
  std::condition_variable buffer_available;
  std::deque<cv::Mat> queued;
  std::vector<cv::Mat> spare;
  size_t allocated = 0;
  bool finishing = false;
};
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
int main(
    int argc,
    char** argv
) try {
  for (int i = 1; i < argc; ++i) {
    const std::string arg = argv[i];
    if (arg == "--input" && i + 1 < argc) {
      INPUT_PATH = argv[++i];
    } else if (arg == "--output" && i + 1 < argc) {
      OUTPUT_PATH = argv[++i];
    } else if (arg == "--help" || arg == "-h") {
      std::printf(
          "usage: %s --input PATH --output PATH\n"
          "measures teleoperation stream latency from a recording that shows\n"
          "the headset passthrough and the robot camera views of one marker\n"
          "board carrying a spinning diode\n"
          "prints the latency in milliseconds on stdout, nothing else\n"
          "signed as camera - passthrough: positive means the camera view is\n"
          "behind the live passthrough by that much\n",
          argv[0]
      );
      return 0;
    } else {
      throw std::runtime_error("unknown argument: " + arg);
    }
  }

  cv::theRNG().state = RANDOM_SEED;
  mallopt(M_MMAP_THRESHOLD, 256 * 1024);
  mallopt(M_TRIM_THRESHOLD, 256 * 1024);
  const VideoInfo info = probe_video(INPUT_PATH);
  detect_view_layout(INPUT_PATH);
  main_stream(INPUT_PATH, OUTPUT_PATH, info);
  return 0;
} catch (const std::exception& failure) {
  std::fprintf(stderr, "%s\n", failure.what());
  return 1;
}
